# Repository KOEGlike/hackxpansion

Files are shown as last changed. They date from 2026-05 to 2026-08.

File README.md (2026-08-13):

> [!CAUTION]
> This repo has been moved to [hackclub/hackxpansion](https://github.com/hackclub/hackxpansion)

<h1 align="center">
    Hackxpansion
</h1>

<h3 align="center">
    <a href="https://hackxpansion.hackclub.com">Website</a>
    <br/>
    <a href="https://meko.fillout.com/hackxpansion">RSVP</a>
</h3>

<h4 align="center">
    A handheld console with 4 expansion solts
</h4>

<div align="center">
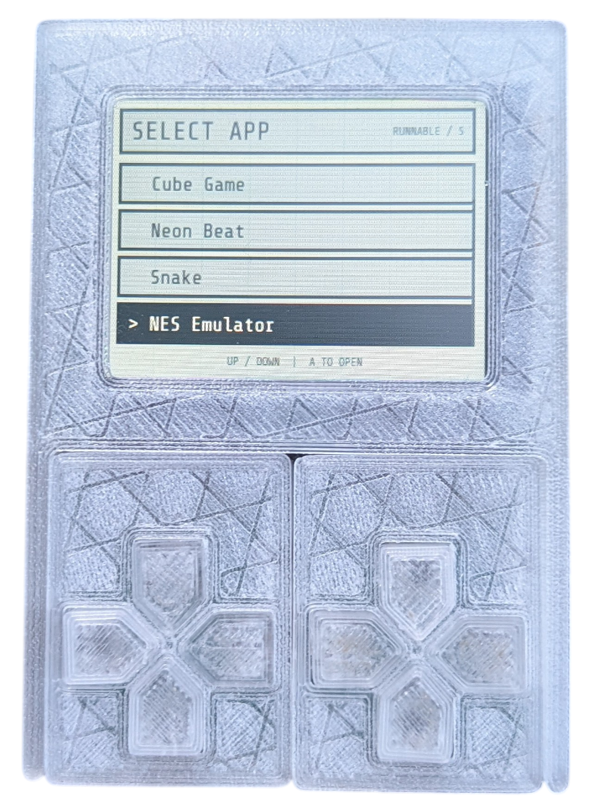
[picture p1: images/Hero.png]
    
</div>

## Key Features

- Resistor based module idnetification at start up
- [2" 240x320 ST7789 LCD panel](https://www.buydisplay.com/2-inch-ips-tft-lcd-display-ips-panel-screen-240x320-for-smart-watch)
- RP2354 MCU
- Easily adaptable [module standard](https://hackxpansion.dino.icu/docs/detailed/card)
- Rust firmware with [embassy](https://embassy.dev/) and [slint-ui](https://slint.dev/)

## Why?

I really like the idea of modules, and modular things, and making people work together, so I made this.

## PCB

The console has two 4 layer PCBs designed in KiCAD, a main-board and a daughter-board, designed for JLC's basic process. 

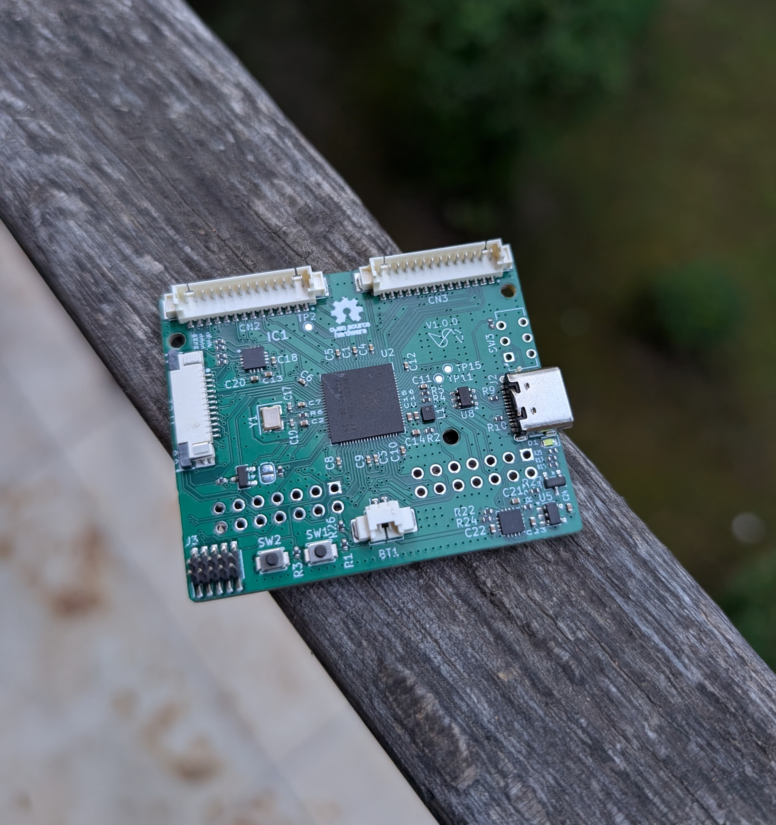
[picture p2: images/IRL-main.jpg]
irl pcb without some connectors and swithc


### Main-Board

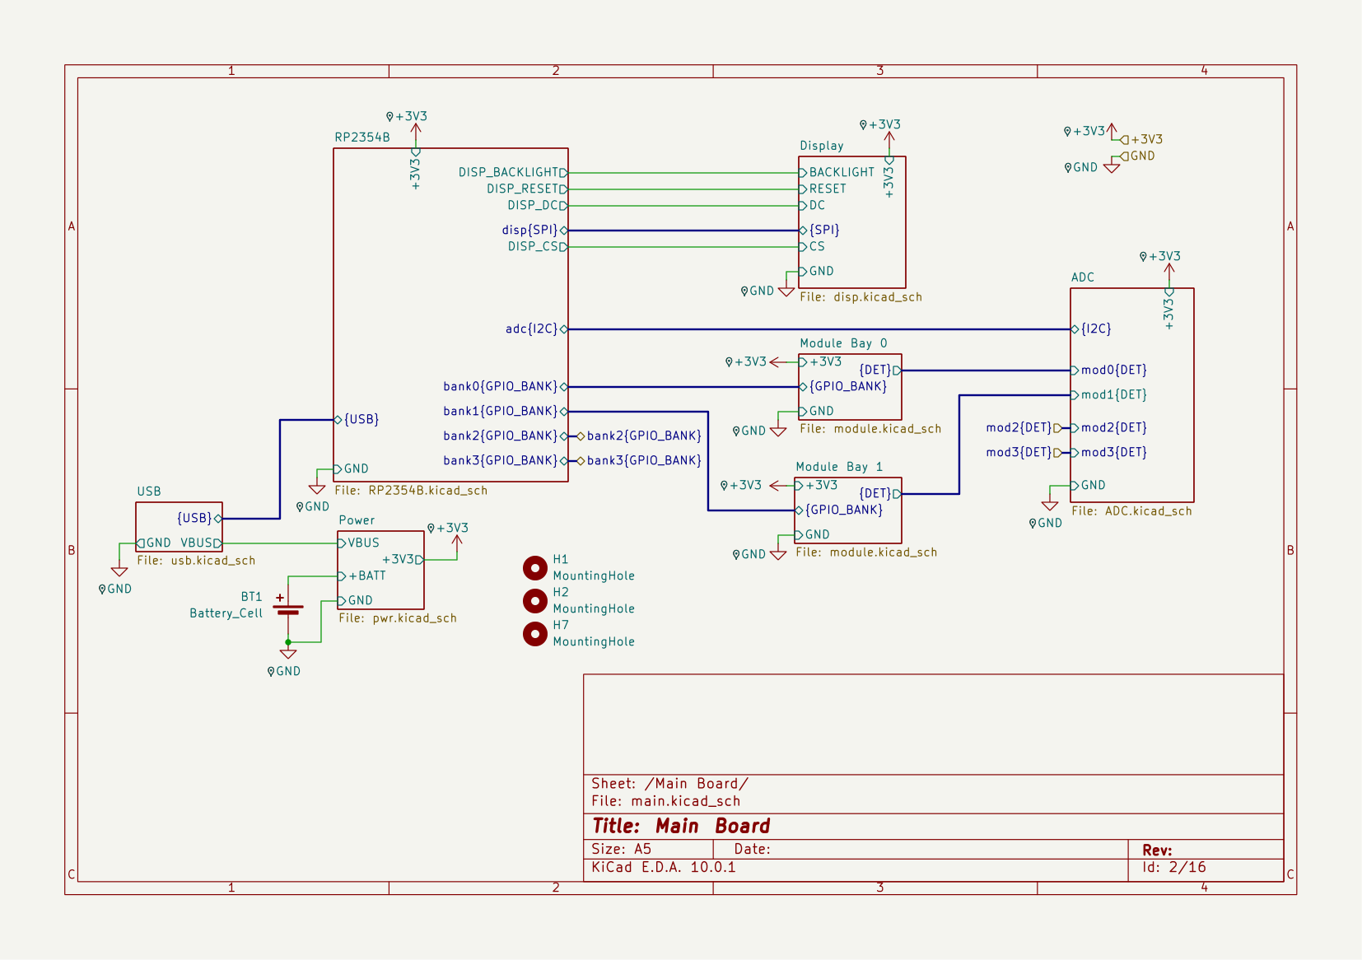
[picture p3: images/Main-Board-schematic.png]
main-board schematic

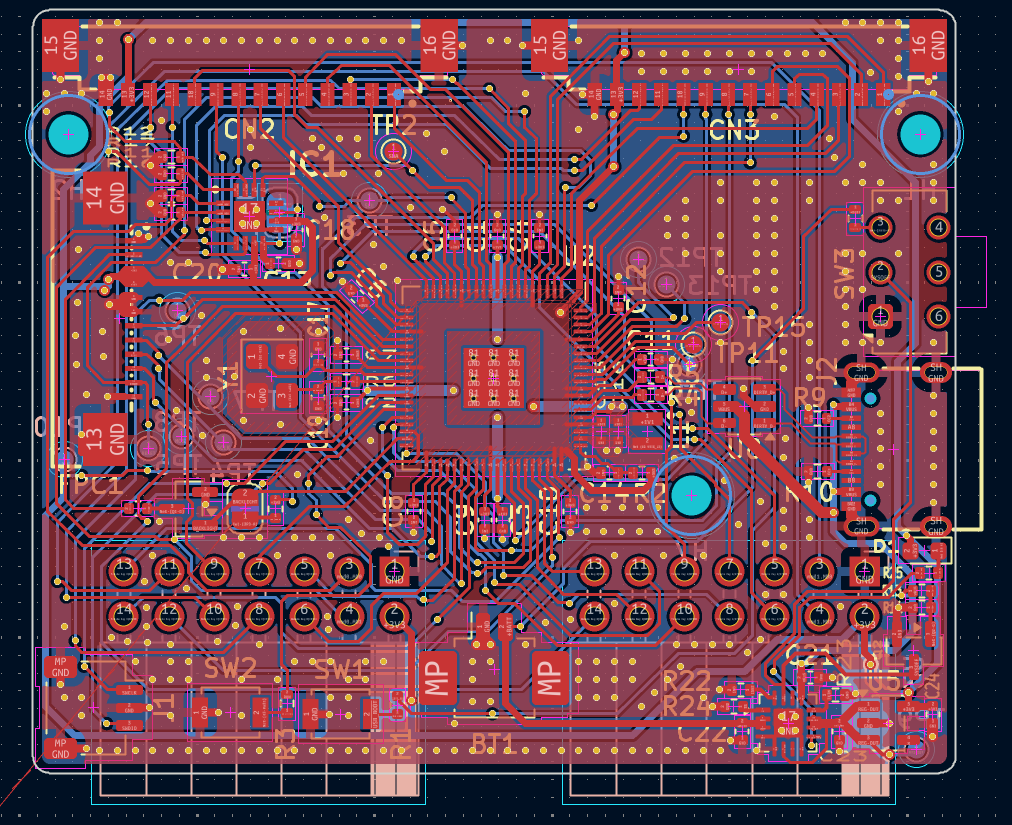
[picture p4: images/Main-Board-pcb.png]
main-board pcb

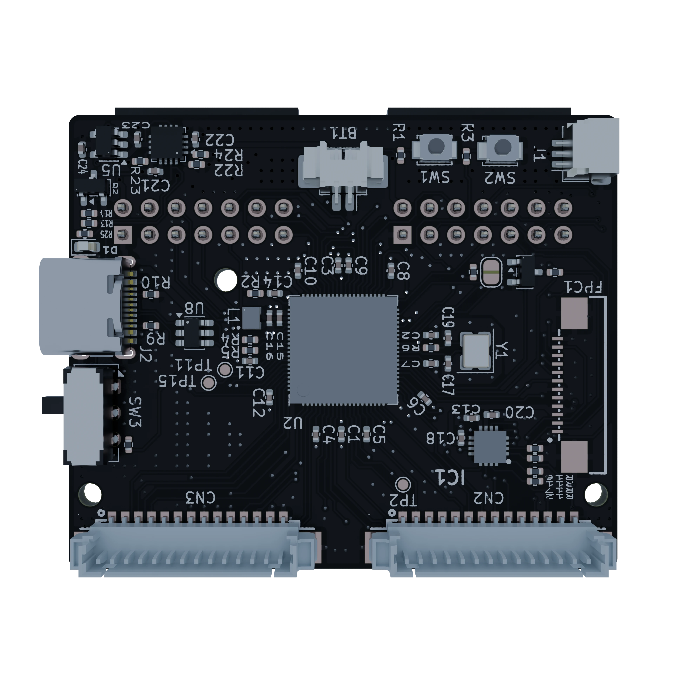
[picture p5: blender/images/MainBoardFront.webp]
main-board render


### Daughter-Board

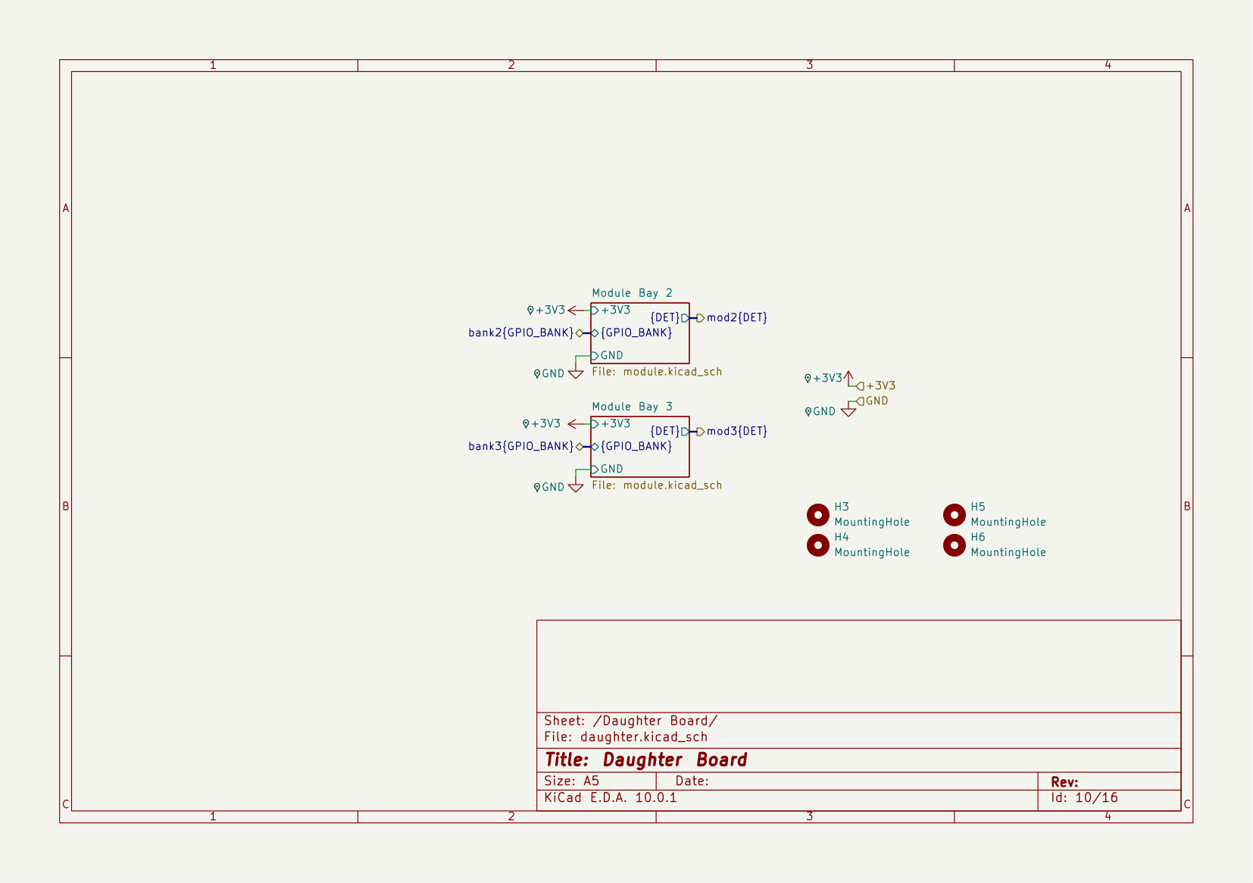
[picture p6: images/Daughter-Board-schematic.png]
daughter-board schematic

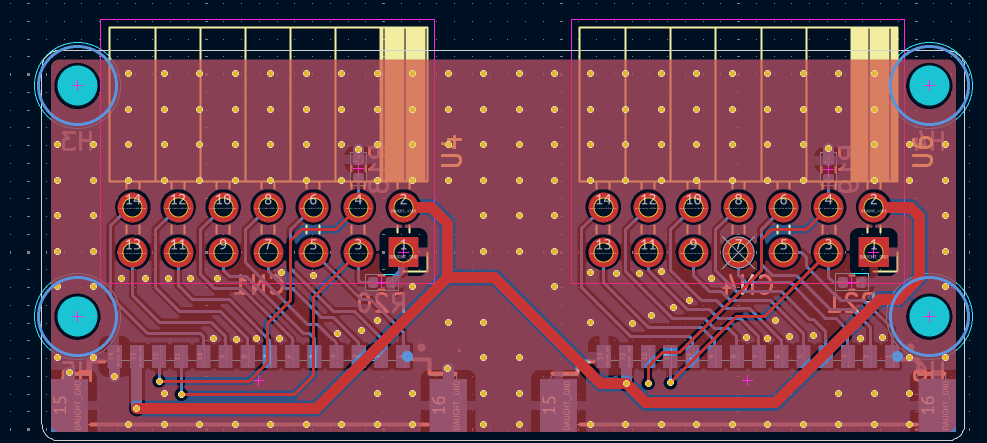
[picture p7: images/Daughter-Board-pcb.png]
daughter-board pcb

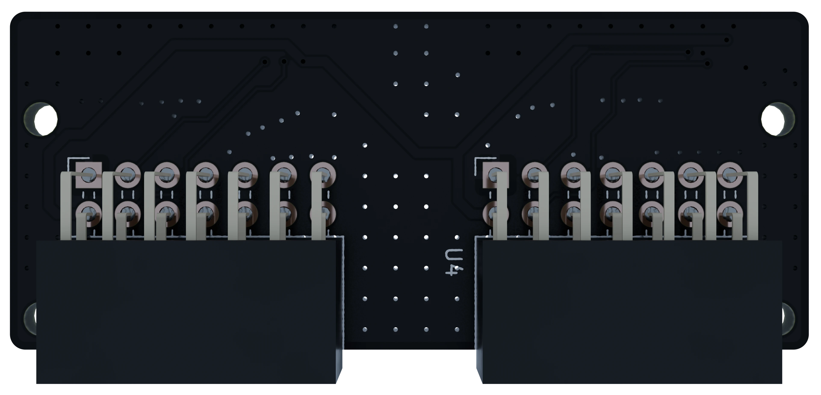
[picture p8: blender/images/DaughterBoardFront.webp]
daughter-board render


## Making Your Own Modules

There are three simple steps to making your own module:

1. Design the module PCB in KiCAD
2. Design the module case in CAD
3. Write a driver for the module

There are detailed docs on the [hackxpansion website](https://hackxpansion.dino.icu/docs)

## Case

The case is designed in Autodesk Fusion, there are .f3z files in the hardware directory.

The models have parameters that can be adjusted to fit your needs.

## Shoutouts

Thank you so much for [Simon](https://github.com/NEOgHacking) who helped with the fanout of the RP, and also gave a ton of constructive feedback!!!!

## Zine

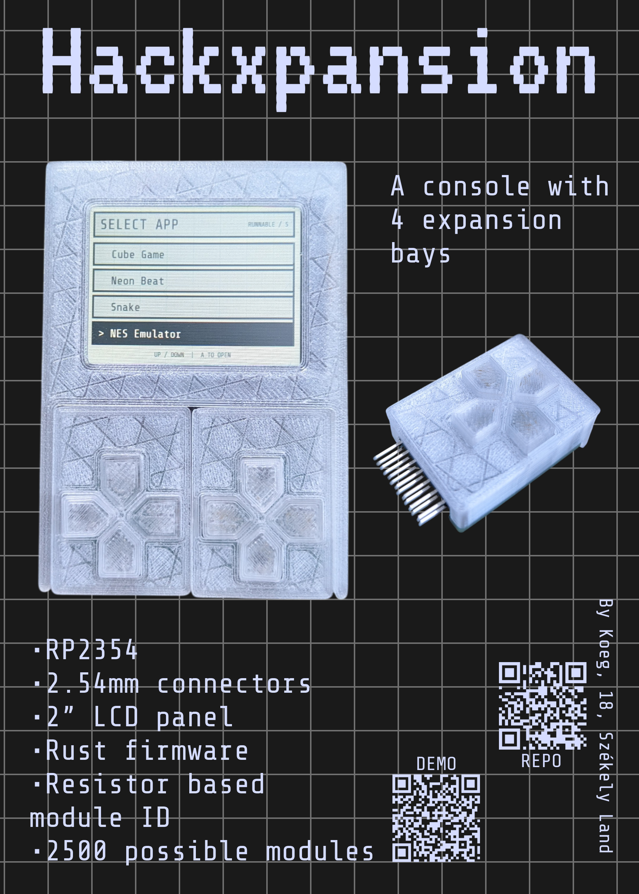
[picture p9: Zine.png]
magazine page


## BOM for Console

This is for an order of 2 PCBA PCBs.

Also found in a [CSV file](hardware/hackxpansion/BOM.csv). Each component has an LCSC part number attached that can be used to find the component on the LCSC website.

|Item |Price per unit|Nr of units|Total price|Link |
|---|---|---|---|---|
|PCB with PCBA |$60.00 |1 |$60.00 |https://jlcpcb.com/ |
|Display |$4.36 |1 |$4.36 |https://www.buydisplay.com/2-inch-ips-tft-lcd-display-ips-panel-screen-240x320-for-smart-watch|
|2x7 2.54mm header |$0.386 |10 |$3.860 |https://www.aliexpress.com/item/1005012166781874.html |
|Battery 502035 |$6.64 |1 |$6.64 |https://www.aliexpress.com/item/1005008218024646.html |
|M2 OD3 L2 heat set insert |$0.0696 |15 |$1.0440 |https://www.aliexpress.com/item/1005006798286851.html |
|M2 L6 screw |$0.0766 |5 |$0.3830 |https://www.aliexpress.com/item/4000970993800.html |
|M2 L8 screw |$0.0766 |2 |$0.1532 |https://www.aliexpress.com/item/4000970993800.html |
|M2 L4 screw |$0.0766 |8 |$0.6128 |https://www.aliexpress.com/item/4000970993800.html |
| | |Total: |$77.05 | |

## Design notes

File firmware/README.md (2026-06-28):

# Xpanse

> [!WARNING]  
> This is still under development and may contain bugs and the api may change, and many parts aren't documented.

This is the firmware for the Hackxpansion console.

The main binary create is called `xpanse`, this is the create the is the heart of the firmware.

The driver api is located in the `xpanse-api` create, this create provides drivers and apps with the necessary traits and types that they need to implement.

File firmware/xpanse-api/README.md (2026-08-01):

# Xpanse API

Shared API for xpanse apps, module drivers, and platform firmware for the [Hackxpansion](https://github.com/KOEGlike/hackxpansion) console

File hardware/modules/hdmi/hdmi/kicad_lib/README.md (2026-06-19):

# Hackxpansion KiCAD Lib

This library contatins the symbols for the male and female module connectors

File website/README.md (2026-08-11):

# Hackxpansion Website

SvelteKit website for the landing page, documentation, authenticated project tracking, and Ari
review integration.

## Requirements

- Node.js 22.12 or newer
- PostgreSQL 18
- Docker (user needs to be added to docker user group)

## Development

Install dependencies and configure the variables documented in `.env.example`. Start the local
database and apply the current Drizzle schema:

```sh
npm install
npm run db:start
npm run db:migrate
```

Then start SvelteKit:

```sh
npm run dev
```

Use `npm run db:generate` when creating a new migration from the current schema. Commit the generated
SQL and metadata together.

## Production

The application requires a Node server for authentication, database-backed pages, form actions, and
Ari webhooks. It cannot be hosted as a static GitHub Pages site.

```sh
npm ci
npm run build
ORIGIN=https://example.com HOST=127.0.0.1 PORT=3000 npm start
```

Set `BASE_PATH` while building when the server is mounted below the origin root. Place a reverse
proxy in front of the Node process for TLS and configure it to forward the original host and protocol.

Set `DATABASE_URL` to the managed PostgreSQL URL. If the deployment platform reserves or overrides
`DATABASE_URL`, set `APP_DATABASE_URL` instead; it takes precedence for migrations and the app.

Deploy production from the root `Dockerfile`. The container applies pending Drizzle migrations
before starting the server, serializing concurrent starts with a PostgreSQL advisory lock.

## Local Docker Compose

Configure `.env`, then build and start the app and local PostgreSQL database:

```sh
docker compose up --build -d
```

The application container applies pending Drizzle migrations before starting the server. Concurrent
starts are serialized with a PostgreSQL advisory lock. The application stack can be started with
`npm run compose:up`.

The app is served at `http://localhost:3000` by default. Set `APP_PORT` to change the host port:

```sh
APP_PORT=8080 docker compose up --build -d
```

Set `ORIGIN` to the public application URL in the runtime environment when deploying the Docker
image.

Generate and commit a new migration with `npm run db:generate` whenever the schema changes.

The initial migration expects a fresh database. A database previously initialized with `db:push`
has no Drizzle migration history; recreate that database or baseline it before enabling automatic
migrations if its existing data must be preserved.

## Quality Checks

```sh
npm run check
npm run lint
npm test
```

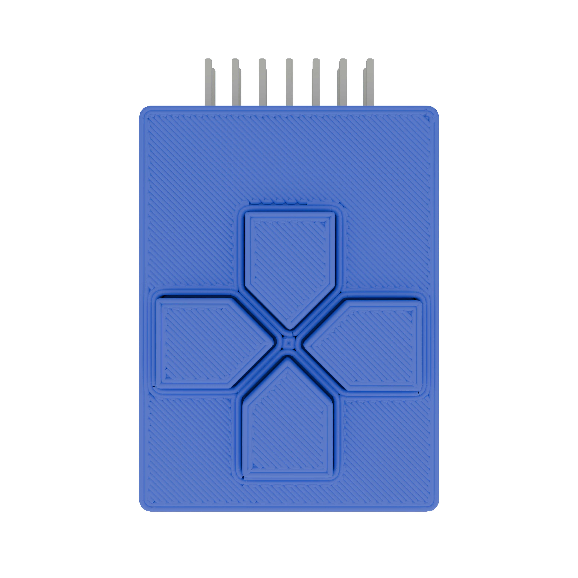
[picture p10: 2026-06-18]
blender/images/ModuleTopView.webp

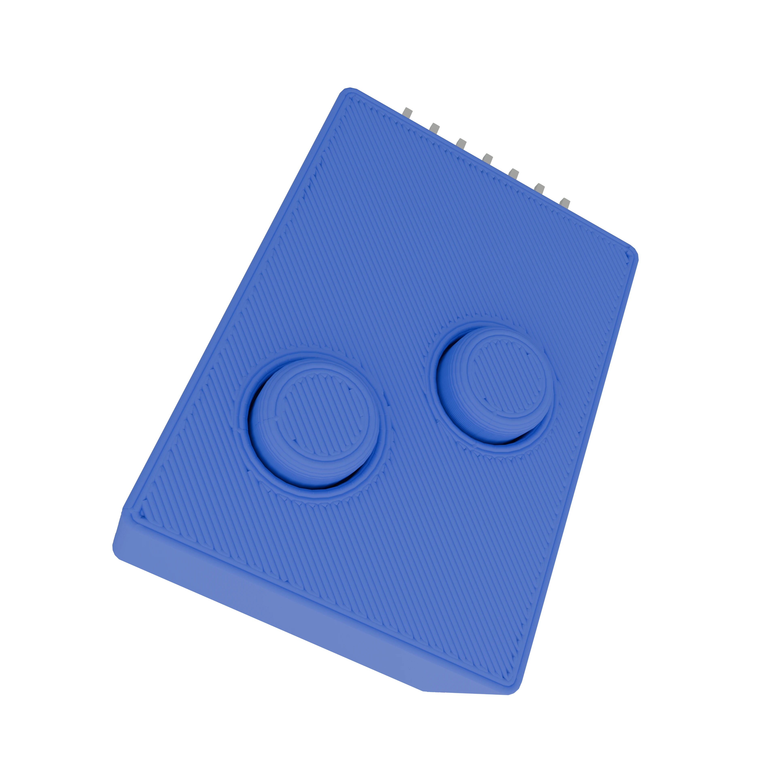
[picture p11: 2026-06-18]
blender/images/TwoButton.webp

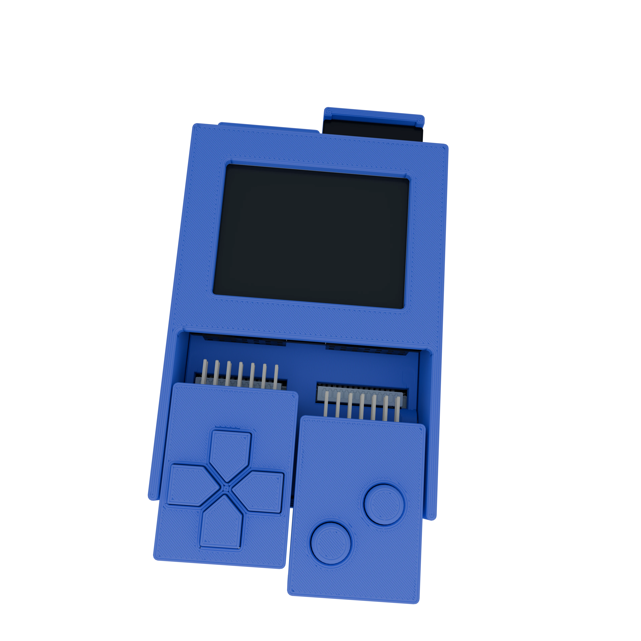
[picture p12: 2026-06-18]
blender/images/Hero.webp

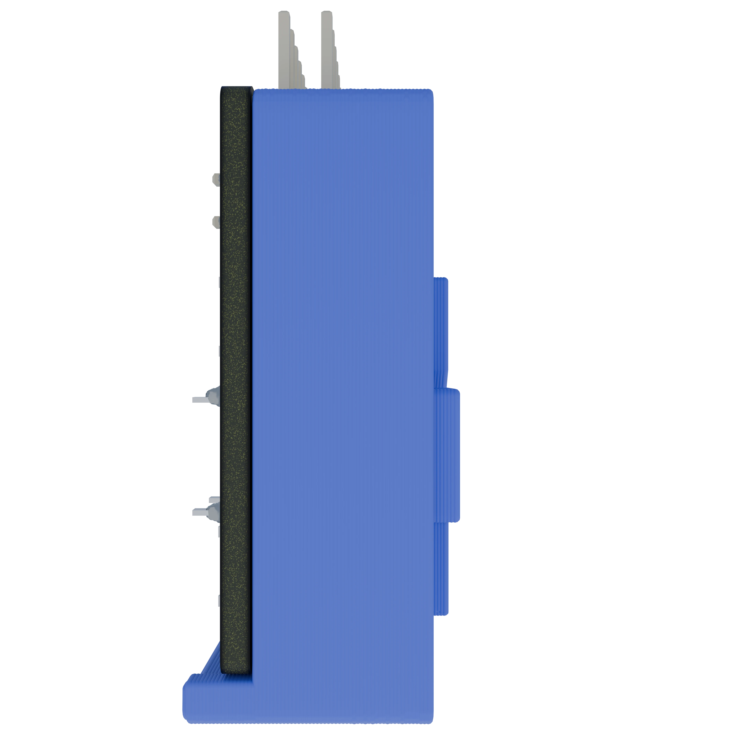
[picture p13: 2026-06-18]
blender/images/ModuleSideView.webp

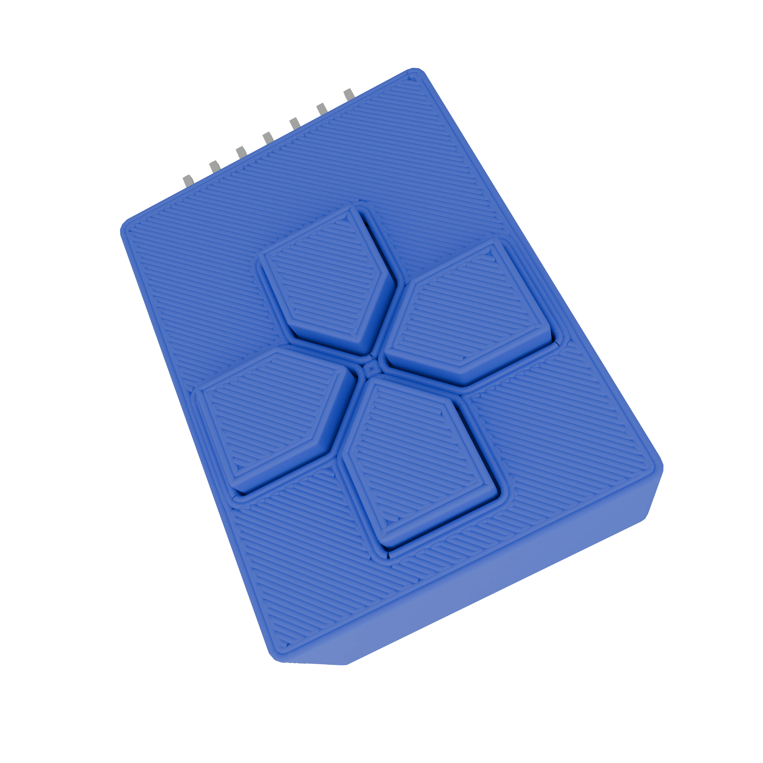
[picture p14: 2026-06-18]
blender/images/DPad.webp

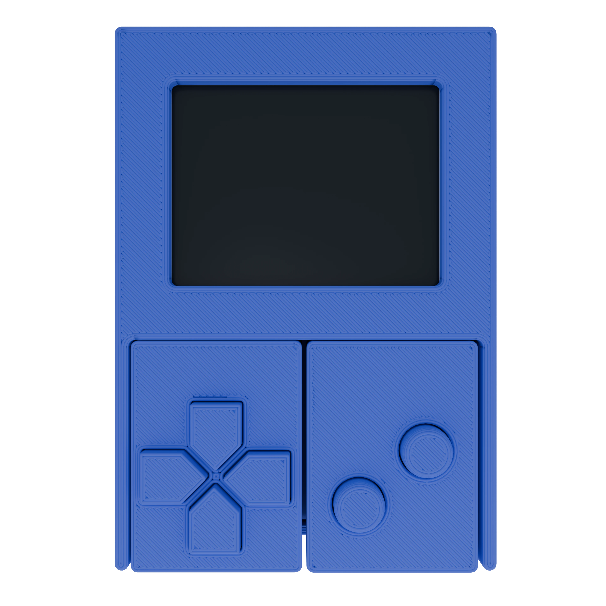
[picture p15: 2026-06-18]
blender/images/TopView.webp

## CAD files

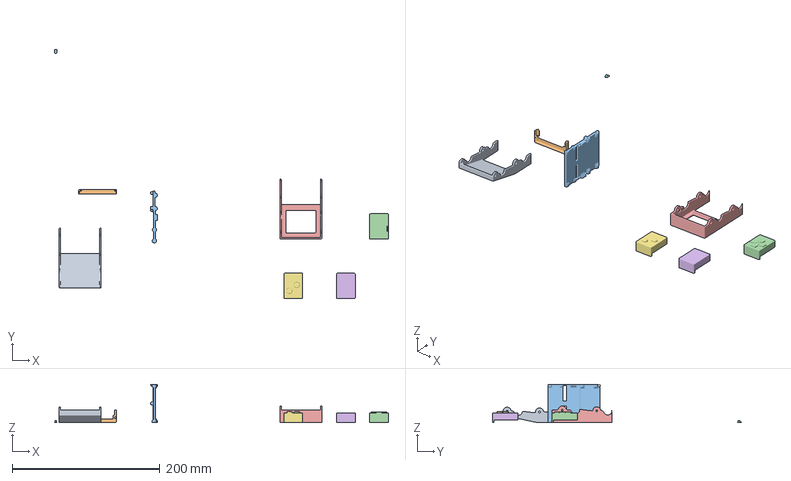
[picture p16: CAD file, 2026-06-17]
blender/gcode/prusa_project.3mf
452.4 x 337.8 x 52.0 mm
Back Shell
Battery Retainer
Core Plate
Four Button Module
Front Shell
empry Case
Two Button
Switch Cover

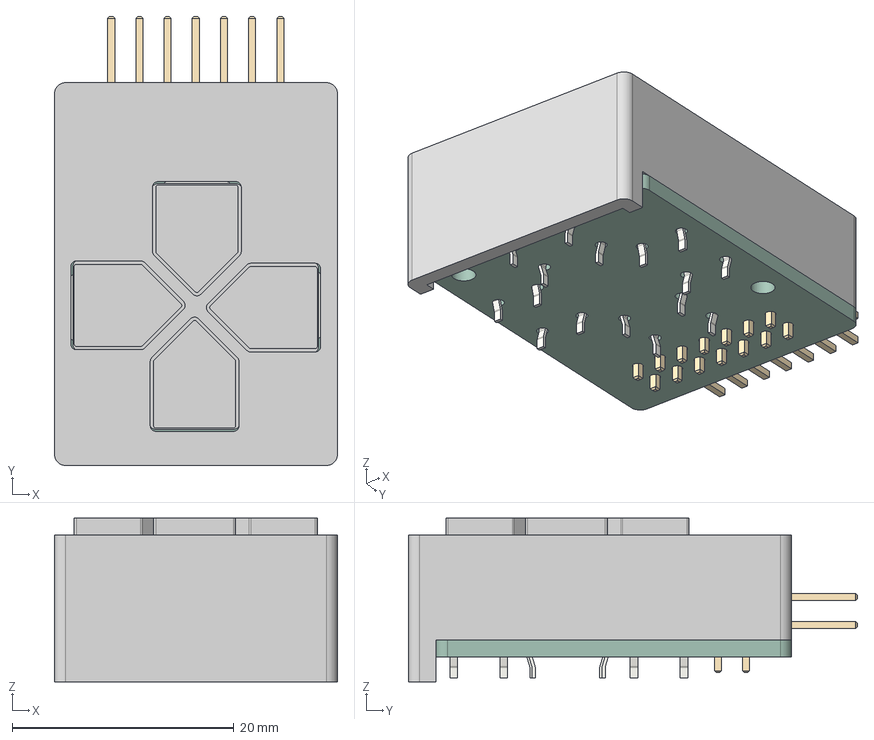
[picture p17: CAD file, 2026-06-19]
hardware/modules/four_button/Four Button Module.step
25.5 x 40.5 x 14.8 mm
PinHeader_2x07_P2.54mm_Horizontal
R_0805_2012Metric x 2
SW_PUSH_6mm x 4
four_button_PCB
Case
Button x 4

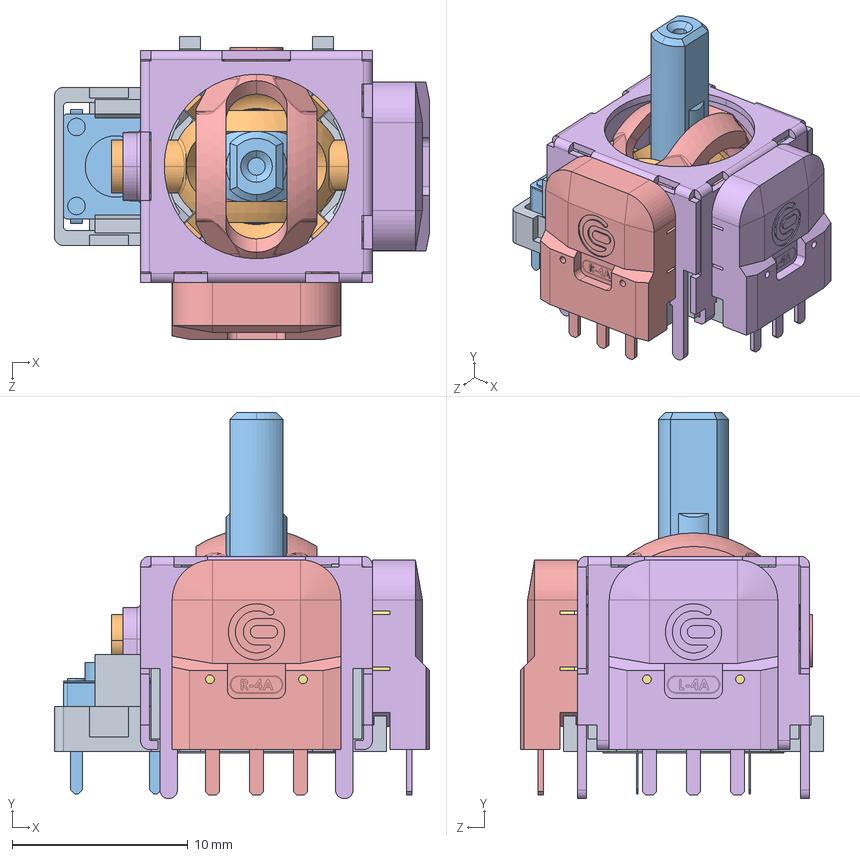
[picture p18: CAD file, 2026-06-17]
hardware/modules/joystick/pcb/Joystick_Hall_PS4.STEP
21.3 x 22.0 x 17.3 mm
Base
Resorte
Pulsador 6x6 5mm
Muelle
X
Stich
Base_Iman - Negro
Iman x 2
Y
Base_Iman
Palo
Eje
Sensor_Negro
Sensor

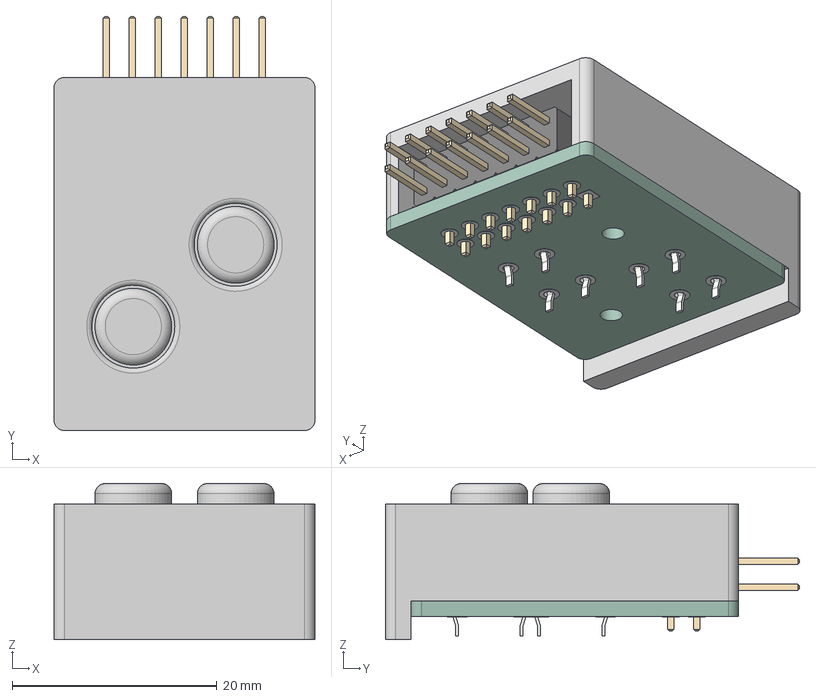
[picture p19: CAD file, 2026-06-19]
hardware/modules/two_button/Two Button.step
25.5 x 40.5 x 15.2 mm
PinHeader_2x07_P2.54mm_Horizontal
R_0805_2012Metric x 2
SW_PUSH_6mm x 2
two_button_pad
two_button_silkscreen
two_button_PCB
Case
Button Cap x 2

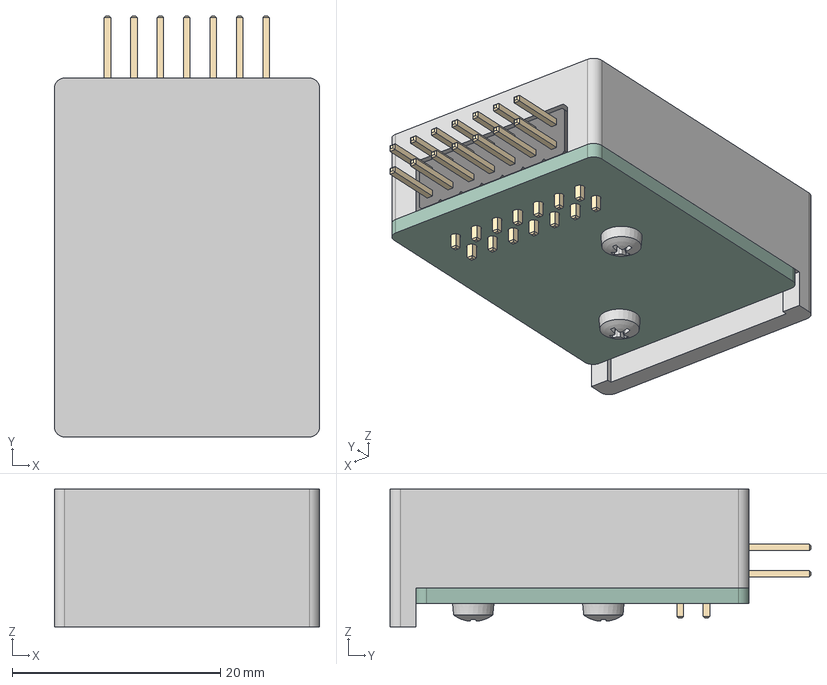
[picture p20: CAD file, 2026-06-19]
hardware/tutorials/audio_module/audio_module.step
25.5 x 40.5 x 13.2 mm
PinHeader_2x07_P2.54mm_Horizontal
R_0805_2012Metric x 2
empty_PCB
Case
DIN 7985 - M2x5-H H Steel 4.6 Plain x 2

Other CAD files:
blender/hackxpansion.blend
hardware/hackxpansion/Main.f3z
hardware/modules/four_button/Four Button Module.f3d
hardware/modules/joystick/pcb/Joystick_Hall_PS4.IGS
hardware/modules/two_button/Two Button.f3d
hardware/tutorials/audio_module/audio_module.f3z
website/animation/anim.blend
website/animation/mockup.f3d

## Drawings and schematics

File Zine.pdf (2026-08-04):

# Hackxpansion

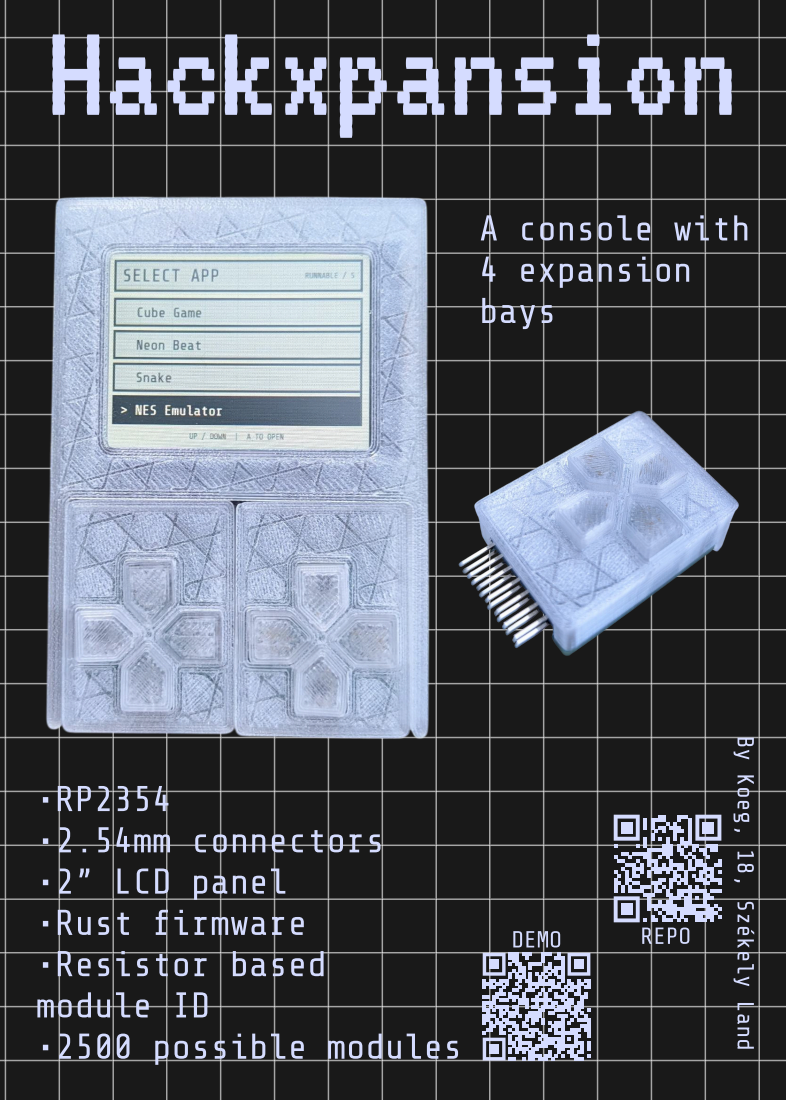
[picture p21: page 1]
A console; with; 4 expansion bays; •RP2354 •2.54mm connectors •2” LCD panel •Rust firmware •Resistor based module ID •2500 possible modules; DEMO; REPO

By Koeg, 18, Székely Land

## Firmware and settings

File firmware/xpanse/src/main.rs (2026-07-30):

#![no_std]
#![no_main]

extern crate alloc;

use defmt::*;
use embassy_executor::Executor;
use embassy_rp::multicore::{Stack, spawn_core1};
use embedded_alloc::LlffHeap as Heap;
use static_cell::StaticCell;
use xpanse::{
    core_app::ui_core_task, core_driver::app_core_task, resource_split::*, split_resources,
};
use {defmt_rtt as _, panic_probe as _};

// Program metadata for `picotool info`.
// This isn't needed, but it's recommended to have these minimal entries.
#[unsafe(link_section = ".bi_entries")]
#[used]
pub static PICOTOOL_ENTRIES: [embassy_rp::binary_info::EntryAddr; 4] = [
    embassy_rp::binary_info::rp_program_name!(c"Hackxpansion"),
    embassy_rp::binary_info::rp_program_description!(c"Firmware for Hackxpansion"),
    embassy_rp::binary_info::rp_cargo_version!(),
    embassy_rp::binary_info::rp_program_build_attribute!(),
];

static mut CORE1_STACK: Stack<16384> = Stack::new();
static EXECUTOR0: StaticCell<Executor> = StaticCell::new();
static EXECUTOR1: StaticCell<Executor> = StaticCell::new();

#[global_allocator]
static HEAP: Heap = Heap::empty();
const HEAP_SIZE: usize = 64 * 1024;

#[cortex_m_rt::entry]
fn main() -> ! {
    let p = embassy_rp::init(Default::default());
    info!("boot: RP235x peripherals initialized");

    let r = split_resources!(p);
    info!("boot: board resources assigned");

    unsafe {
        embedded_alloc::init!(HEAP, HEAP_SIZE);
    }
    info!("boot: {} KiB heap initialized", HEAP_SIZE / 1024);

    info!("boot: starting core 1");
    spawn_core1(
        p.CORE1,
        unsafe { &mut *core::ptr::addr_of_mut!(CORE1_STACK) },
        move || {
            let executor1 = EXECUTOR1.init(Executor::new());
            executor1.run(|spawner| {
                spawner.spawn(unwrap!(app_core_task(
                    r.gpio_bank_0,
                    r.gpio_bank_1,
                    r.gpio_bank_2,
                    r.gpio_bank_3,
                    r.i2c_pins,
                    r.remaining_peris
                )))
            });
        },
    );
    info!("boot: core 1 launched");

    info!("boot: starting core 0 UI executor");
    let executor0 = EXECUTOR0.init(Executor::new());
    executor0.run(|spawner| spawner.spawn(unwrap!(ui_core_task(r.display))));
}

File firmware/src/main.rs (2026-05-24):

//! This example test the RP Pico on board LED.
//!
//! It does not work with the RP Pico W board. See `blinky_wifi.rs`.

#![no_std]
#![no_main]

use defmt::*;
use embassy_executor::Spawner;
use embassy_rp::gpio;
use embassy_time::Timer;
use gpio::{Level, Output};
use heapless::String;
use {defmt_rtt as _, panic_probe as _};

// Program metadata for `picotool info`.
// This isn't needed, but it's recommended to have these minimal entries.
#[unsafe(link_section = ".bi_entries")]
#[used]
pub static PICOTOOL_ENTRIES: [embassy_rp::binary_info::EntryAddr; 4] = [
    embassy_rp::binary_info::rp_program_name!(c"Hackxpansion"),
    embassy_rp::binary_info::rp_program_description!(
        c"This example tests the RP Pico on board LED, connected to gpio 25"
    ),
    embassy_rp::binary_info::rp_cargo_version!(),
    embassy_rp::binary_info::rp_program_build_attribute!(),
];

#[embassy_executor::main]
async fn main(_spawner: Spawner) {
    let p = embassy_rp::init(Default::default());
    let mut led = Output::new(p.PIN_25, Level::Low);

    loop {
        info!("led on!");
        led.set_high();
        Timer::after_millis(250).await;

        info!("led off!");
        led.set_low();
        Timer::after_millis(250).await;
    }
}

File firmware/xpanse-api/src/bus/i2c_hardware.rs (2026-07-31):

//! RP235x hardware I2C backend, interrupt-driven with no DMA.
//!
//! The platform normally constructs these buses through
//! [`BusAllocator::create_i2c_hardware`](crate::bus::allocator::BusAllocator::create_i2c_hardware).
use alloc::vec::Vec;

use crate::bus::i2c::I2cError;
use embassy_rp::Peri;
use embassy_rp::i2c::{self, Async, Config, I2c, Instance, InterruptHandler};
use embassy_rp::interrupt::typelevel::Binding;

/// Interrupt-driven RP235x I2C bus implementing
/// [`embedded_hal_async::i2c::I2c`] for `I2cBusHandle`.
pub struct HardwareI2cBus<'d, I: Instance> {
    i2c: I2c<'d, I, Async>,
}

impl<'d, I: Instance> HardwareI2cBus<'d, I> {
    /// Validates an I2C configuration against the running peripheral clock.
    ///
    /// Returns [`I2cError::Other`] when the frequency and derived divider counts
    /// fall outside the hardware's representable range.
    pub fn validate_config(config: &Config) -> Result<(), I2cError> {
        if config.frequency == 0 || config.frequency > 1_000_000 {
            return Err(I2cError::Other);
        }

        let clock = embassy_rp::clocks::clk_peri_freq();
        let period = (clock + config.frequency / 2) / config.frequency;
        let low_count = period * 3 / 5;
        let high_count = period - low_count;
        if high_count < 8 || low_count < 8 || high_count > 0xffff || low_count > 0xffff {
            return Err(I2cError::Other);
        }

        let sda_hold_count = if config.frequency < 1_000_000 {
            ((clock * 3) / 10_000_000) + 1
        } else {
            if clock <= 32_000_000 {
                return Err(I2cError::Other);
            }
            ((clock * 3) / 25_000_000) + 1
        };
        if sda_hold_count > low_count - 2 {
            return Err(I2cError::Other);
        }

        Ok(())
    }

    /// Builds an I2C bus from a previously validated configuration.
    ///
    /// `scl` and `sda` are role-checked against `I` at compile time, and `irq`
    /// is the board's `bind_interrupts!` binding for the I2C interrupt.
    pub fn new<Irq>(
        peri: Peri<'d, I>,
        scl: Peri<'d, impl i2c::SclPin<I> + 'd>,
        sda: Peri<'d, impl i2c::SdaPin<I> + 'd>,
        irq: Irq,
        config: Config,
    ) -> Result<Self, I2cError>
    where
        Irq: Binding<I::Interrupt, InterruptHandler<I>> + 'd,
    {
        Self::validate_config(&config)?;
        let i2c = I2c::new_async(peri, scl, sda, irq, config);
        Ok(Self { i2c })
    }
}

impl<'d, I: Instance> embedded_hal::i2c::ErrorType for HardwareI2cBus<'d, I> {
    type Error = I2cError;
}

impl<'d, I: Instance> embedded_hal_async::i2c::I2c<embedded_hal::i2c::SevenBitAddress>
    for HardwareI2cBus<'d, I>
{
    async fn read(
        &mut self,
        address: embedded_hal::i2c::SevenBitAddress,
        read: &mut [u8],
    ) -> Result<(), I2cError> {
        if address > 0x7f {
            return Err(I2cError::AddressOutOfRange);
        }
        if read.is_empty() {
            return Err(I2cError::InvalidBufferLength);
        }
        self.i2c.read(address, read).await.map_err(I2cError::from)
    }

    async fn write(
        &mut self,
        address: embedded_hal::i2c::SevenBitAddress,
        write: &[u8],
    ) -> Result<(), I2cError> {
        if address > 0x7f {
            return Err(I2cError::AddressOutOfRange);
        }
        if write.is_empty() {
            return Err(I2cError::InvalidBufferLength);
        }
        self.i2c.write(address, write).await.map_err(I2cError::from)
    }

    async fn write_read(
        &mut self,
        address: embedded_hal::i2c::SevenBitAddress,
        write: &[u8],
        read: &mut [u8],
    ) -> Result<(), I2cError> {
        if address > 0x7f {
            return Err(I2cError::AddressOutOfRange);
        }
        if write.is_empty() || read.is_empty() {
            return Err(I2cError::InvalidBufferLength);
        }
        self.i2c
            .write_read(address, write, read)
            .await
            .map_err(I2cError::from)
    }

    async fn transaction(
        &mut self,
        address: embedded_hal::i2c::SevenBitAddress,
        operations: &mut [embedded_hal::i2c::Operation<'_>],
    ) -> Result<(), I2cError> {
        if address > 0x7f {
            return Err(I2cError::AddressOutOfRange);
        }
        if operations.iter().any(|operation| match operation {
            embedded_hal::i2c::Operation::Read(buf) => buf.is_empty(),
            embedded_hal::i2c::Operation::Write(buf) => buf.is_empty(),
        }) {
            return Err(I2cError::InvalidBufferLength);
        }
        if operations.is_empty() {
            return Ok(());
        }

        let mut seen_read = false;
        let mut write_len = 0;
        let mut read_len = 0;
        for operation in operations.iter() {
            match operation {
                embedded_hal::i2c::Operation::Write(bytes) if !seen_read => {
                    write_len += bytes.len();
                }
                embedded_hal::i2c::Operation::Read(bytes) => {
                    seen_read = true;
                    read_len += bytes.len();
                }
                embedded_hal::i2c::Operation::Write(_) => {
                    // The public Embassy API cannot continue an atomic transaction
                    // after a read phase, so reject rather than insert a STOP.
                    return Err(I2cError::UnsupportedTransaction);
                }
            }
        }

        let mut write_buffer = Vec::with_capacity(write_len);
        for operation in operations.iter() {
            if let embedded_hal::i2c::Operation::Write(bytes) = operation {
                write_buffer.extend_from_slice(bytes);
            }
        }

        if read_len == 0 {
            return self
                .i2c
                .write(address, &write_buffer)
                .await
                .map_err(I2cError::from);
        }

        let mut read_buffer = alloc::vec![0; read_len];
        if write_len == 0 {
            self.i2c
                .read(address, &mut read_buffer)
                .await
                .map_err(I2cError::from)?;
        } else {
            self.i2c
                .write_read(address, &write_buffer, &mut read_buffer)
                .await
                .map_err(I2cError::from)?;
        }

        let mut offset = 0;
        for operation in operations.iter_mut() {
            if let embedded_hal::i2c::Operation::Read(bytes) = operation {
                let end = offset + bytes.len();
                bytes.copy_from_slice(&read_buffer[offset..end]);
                offset = end;
            }
        }
        Ok(())
    }
}

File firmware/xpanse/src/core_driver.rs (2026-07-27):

use xpanse_api::gpio_bank::GpioBank;
use xpanse_api::registry::Registry;

use crate::load_driver::load_driver;
use crate::{adc::init_adc, adc_mapping, resource_split::*};
use xpanse_api::bus::allocator::BusAllocator;
use xpanse_api::interfaces::adc;
use xpanse_api::interfaces::usb::UsbPeripheral;
use xpanse_api::metadata::{ModuleID, ModuleSlot};

use embassy_sync::{blocking_mutex::raw::CriticalSectionRawMutex, signal::Signal};
use embassy_time::{Duration, Timer, with_timeout};

const MODULE_DETECTION_TIMEOUT: Duration = Duration::from_millis(100);

macro_rules! gpio_bank_from_peris {
    ($peri:expr) => {
        GpioBank::new(
            $peri.gpio0,
            $peri.gpio1,
            $peri.gpio2,
            $peri.gpio3,
            $peri.gpio4,
            $peri.gpio5,
            $peri.gpio6,
            $peri.gpio7,
            $peri.gpio8,
            $peri.gpio9,
            $peri.pwm_slice1,
            $peri.pwm_slice2,
            $peri.pwm_slice3,
        )
    };
}

static REGISTRY_HANDOFF: Signal<CriticalSectionRawMutex, Registry> = Signal::new();

pub async fn take_registry() -> Registry {
    REGISTRY_HANDOFF.wait().await
}

#[embassy_executor::task]
pub async fn app_core_task(
    gpio_bank_0: GpioBankPeris0,
    gpio_bank_1: GpioBankPeris1,
    gpio_bank_2: GpioBankPeris2,
    gpio_bank_3: GpioBankPeris3,
    mut i2c_pins: I2cPinPeris,
    remaining_peris: RemainingPeris,
) {
    defmt::info!("app_core: started on core 1");

    let gpio_bank_0 = gpio_bank_from_peris!(gpio_bank_0);
    let gpio_bank_1 = gpio_bank_from_peris!(gpio_bank_1);
    let gpio_bank_2 = gpio_bank_from_peris!(gpio_bank_2);
    let gpio_bank_3 = gpio_bank_from_peris!(gpio_bank_3);
    defmt::info!("app_core: GPIO banks initialized");

    defmt::info!("app_core: initializing module-detection ADC");
    let module_ids = {
        let module_adc = match init_adc(i2c_pins.sda.reborrow(), i2c_pins.scl.reborrow()).await {
            Ok(adc) => {
                defmt::info!("app_core: module-detection ADC initialized");
                Some(adc)
            }
            Err(error) => {
                defmt::error!(
                    "app_core: module-detection ADC initialization failed: {:?}",
                    error
                );
                None
            }
        };

        match module_adc {
            Some(mut module_adc) => {
                let front_right = detect_module(&mut module_adc, ModuleSlot::FrontRight).await;
                let front_left = detect_module(&mut module_adc, ModuleSlot::FrontLeft).await;
                let back_right = detect_module(&mut module_adc, ModuleSlot::BackRight).await;
                let back_left = detect_module(&mut module_adc, ModuleSlot::BackLeft).await;
                [front_right, front_left, back_right, back_left]
            }
            None => [None; 4],
        }
    };

    defmt::info!("app_core: initializing internal ADC");
    adc::init_adc(remaining_peris.adc, remaining_peris.adc_temp);
    defmt::info!("app_core: internal ADC initialized");

    defmt::info!("app_core: creating bus allocator");
    let mut bus_allocator = BusAllocator::new(
        None,
        Some(remaining_peris.spi1),
        Some(remaining_peris.i2c0),
        Some(remaining_peris.i2c1),
        Some(remaining_peris.uart0),
        Some(remaining_peris.uart1),
        xpanse_api::bus::allocator::DmaPool {
            ch0: Some(remaining_peris.dma_ch0),
            ch1: Some(remaining_peris.dma_ch1),
            ch2: Some(remaining_peris.dma_ch2),
            ch3: Some(remaining_peris.dma_ch3),
            ch4: Some(remaining_peris.dma_ch4),
            ch5: Some(remaining_peris.dma_ch5),
            ch6: Some(remaining_peris.dma_ch6),
            ch7: Some(remaining_peris.dma_ch7),
            ch8: Some(remaining_peris.dma_ch8),
            ch9: Some(remaining_peris.dma_ch9),
            ch10: Some(remaining_peris.dma_ch10),
            ch11: Some(remaining_peris.dma_ch11),
            ch12: Some(remaining_peris.dma_ch12),
            ch13: Some(remaining_peris.dma_ch13),
            ch14: Some(remaining_peris.dma_ch14),
            ch15: Some(remaining_peris.dma_ch15),
        },
        remaining_peris.pio0,
        remaining_peris.pio1,
        remaining_peris.pio2,
    );

    let mut registry = Registry::new();
    registry.register_platform::<UsbPeripheral>(remaining_peris.usb);

    defmt::info!("app_core: loading module drivers");
    load_driver(
        module_ids[0],
        gpio_bank_0,
        ModuleSlot::FrontRight,
        &mut registry,
        &mut bus_allocator,
    )
    .await;
    load_driver(
        module_ids[1],
        gpio_bank_1,
        ModuleSlot::FrontLeft,
        &mut registry,
        &mut bus_allocator,
    )
    .await;
    load_driver(
        module_ids[2],
        gpio_bank_2,
        ModuleSlot::BackRight,
        &mut registry,
        &mut bus_allocator,
    )
    .await;
    load_driver(
        module_ids[3],
        gpio_bank_3,
        ModuleSlot::BackLeft,
        &mut registry,
        &mut bus_allocator,
    )
    .await;

    defmt::info!("app_core: drivers loaded, handing registry to core 0");
    REGISTRY_HANDOFF.signal(registry);
}

async fn detect_module(adc: &mut crate::adc::Adc<'_>, slot: ModuleSlot) -> Option<ModuleID> {
    defmt::info!("app_core: detecting module in {:?}", slot);

    for attempt in 1..=3 {
        match with_timeout(MODULE_DETECTION_TIMEOUT, adc_mapping::map_adc(adc, slot)).await {
            Ok(Ok(Some(id))) => {
                defmt::info!("app_core: detected module {:?} in {:?}", id, slot);
                return Some(id);
            }
            Ok(Ok(None)) => {
                defmt::info!("app_core: no module detected in {:?}", slot);
                return None;
            }
            Ok(Err(error)) => defmt::warn!(
                "app_core: module detection attempt {} failed for {:?}: {:?}",
                attempt,
                slot,
                error
            ),
            Err(_) => defmt::warn!(
                "app_core: module detection attempt {} timed out for {:?}",
                attempt,
                slot
            ),
        }
        Timer::after_millis(10).await;
    }
    defmt::error!("app_core: module detection failed for {:?}", slot);
    None
}

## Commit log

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2026-01-29 added mcu and adc
    [hackxpansion.kicad_sch]
2026-03-14 added basic blend file
    [Untitled.blend]
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2026-03-14 moved renders to different folder
    [Untitled.blend]
2026-03-14 added stuff related to loading
    [Untitled.blend, mockup.f3d]
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2026-03-15 updated anim to 60 fps
    [Untitled.blend, anim.blend, mockup.f3d]
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2026-03-15 Added RP2354B and made basic fanout
    [RP2354B.kicad_sch, hackxpansion.kicad_pcb, hackxpansion.kicad_sch]
2026-03-15 More fanout
    Just a little bit further with the fanout of the RP2354B
    [hackxpansion.kicad_pcb]
2026-03-16 Completed fanout
    Completed the fanout for the rp2354B also placed the silkscreen labels in places where you can read them.
    [hackxpansion.kicad_pcb, hackxpansion.kicad_sch]
2026-03-16 ADC Power and input
    Started with the power input and communication for the ADC
    [hackxpansion.kicad_sch]
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2026-03-16 fix: correct frame event start index and adjust element height for better scrolling
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2026-03-16 fix: conditionally render "Go Up" button based on current frame
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2026-03-17 fix: adjust scroll frame rate and update frame event end value
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2026-03-19 Fixed missing stuff and now finally separate sheet for the ADC
    Auto stash before merge of "main" and "origin/main"
    [ADC.kicad_sch, hackxpansion.kicad_sch]
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2026-03-19 feat: replace Scroll component with LandingSection for improved layout
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2026-03-23 Fixed 1V1 trace and added a bit to ADC schematic
    [ADC.kicad_sch, RP2354B.kicad_sch, hackxpansion.kicad_pcb]
2026-03-24 added jlc 2 layer constraints
    [ADC.kicad_sch]
2026-03-24 moved to kicad 10
    [ADC.kicad_sch, RP2354B.kicad_sch, hackxpansion.kicad_pcb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]
2026-03-30 added new adc symbol
    [hackxpansion.kicad_pcb, hackxpansion.kicad_sch]
2026-03-30 finished adding new adc, and started on dispaly
    [ADC.kicad_sch, disp.kicad_sch, hackxpansion.kicad_pcb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]
2026-04-09 STARTED WORKING ON SYMBOL
    [disp.kicad_sch, hackxpansion.kicad_pcb, hackxpansion.kicad_sch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]
2026-04-09 moved stuff around, started on display
    [RP2354B.kicad_sch, disp.kicad_sch]
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2026-04-26 updated power sheet, made module female symbol
    [module.kicad_sch, pwr.kicad_sch]
2026-05-03 removed unused power symbols
    [pwr.kicad_sch]
2026-05-07 worked on io banks
    [ADC.kicad_sch, CONNECTOR.csv, RP2354B.kicad_sch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]
2026-05-07 did a bunch of gpio bank stuff
    [CONNECTOR.csv, RP2354B.kicad_sch, disp.kicad_sch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]
2026-05-17 started to split up the schematic into two pcbs
    [ADC.kicad_sch, RP2354B.kicad_sch, daughter.kicad_sch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]
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2026-05-18 switched to pico blade connectors
    [daughter_conn.kicad_sch, hackxpansion.kicad_pcb, hackxpansion.kicad_sch]
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2026-05-20 updated some stuff on pcb
    [disp.kicad_sch, hackxpansion.kicad_pcb]
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2026-05-21 laid out edge components
    [hackxpansion.kicad_pcb]
2026-05-21 did more layout, added 3d models
    [RP2354B.kicad_sch, disp.kicad_sch, hackxpansion.kicad_pcb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]
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2026-05-22 worked on the pcb
    [ADC.kicad_sch, RP2354B.kicad_sch, disp.kicad_sch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]
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2026-05-23 swapped the module pins around
    [RP2354B.kicad_sch, hackxpansion.kicad_pcb, main.kicad_sch]
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2026-05-28 added some stitching vias
    [hackxpansion.kicad_pcb]
2026-05-28 added more stitching vias
    [hackxpansion.kicad_pcb]
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2026-05-28 laid out secound module
    [hackxpansion.kicad_pcb]
2026-05-29 finished daughter board, added stuff to main board
    added esd and extra mounting hole to mainboard, finished daughter board
    [daughter.kicad_sch, hackxpansion.kicad_pcb, main.kicad_sch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]
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2026-05-30 restructured project, added two button example module
    [ADC.kicad_sch, RP2354B.kicad_sch, daughter.kicad_sch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]
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2026-05-31 removed display brightness control, ran out of pin
    [RP2354B.kicad_sch, disp.kicad_sch, hackxpansion.kicad_pcb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]
2026-06-01 added titles to schematic
    [ADC.kicad_sch, RP2354B.kicad_sch, daughter.kicad_sch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]
2026-06-01 added back display brightness, removed adc allert on pcb
    [ADC.kicad_sch, RP2354B.kicad_sch, disp.kicad_sch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]
2026-06-01 switched the two i2c pins on the rpi for the adc
    [RP2354B.kicad_sch, hackxpansion.kicad_pcb]
2026-06-02 switcheed bank 0 pin 5 and 6 cuz i messed up
    [RP2354B.kicad_sch, hackxpansion.kicad_pcb]
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2026-06-07 added 3d model to rp inductor, moved silkscreen around
    [hackxpansion.kicad_pcb]
2026-06-07 updated footprint 3d model from wrl to step
    [hackxpansion.kicad_pcb]
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2026-06-09 added mounting holes to two button module
    [two_button.kicad_pcb, two_button.kicad_sch]
2026-06-09 moved display connector up 1.6mm
    [hackxpansion.kicad_pcb]
2026-06-10 fixed 3d model for pico blade connector
    [hackxpansion.kicad_pcb]
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2026-06-10 moved usb c 3d to project folder
    [hackxpansion.kicad_pcb]
2026-06-12 moved fpc connector inwords
    [hackxpansion.kicad_pcb]
2026-06-17 added four button module
    [four_button.kicad_pcb, four_button.kicad_sch]
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2026-06-21 added series resistor to module power rail, so it can now do hotswap
    [disp.kicad_sch, hackxpansion.kicad_pcb, module.kicad_sch]
2026-06-23 changed out fpc connector, fixed usb dp width
    [disp.kicad_sch, hackxpansion.kicad_pcb]
2026-06-23 fixed issues with new fpc
    [hackxpansion.kicad_pcb]
2026-06-24 fixed unconnected 3v3 via next to display
    [hackxpansion.kicad_pcb]
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2026-06-27 added a bunch of gnd return VIAs, removed via group
    [hackxpansion.kicad_pcb]
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2026-06-28 added resistor values to the four and two button modules
    [four_button.kicad_sch, two_button.kicad_pcb, two_button.kicad_sch]
2026-06-28 updated two and four button pcb with new lcsc part nums
    [four_button.kicad_pcb, two_button.kicad_pcb]
2026-06-28 updated lcsc part nums for modules with correct footprint
    [four_button.kicad_pcb, four_button.kicad_sch, two_button.kicad_pcb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]
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2026-07-19 let gpt 5.6 sol max loose on the firmware
    I want through all the changes it made, and will fix the issues I found
    in future commits
    [adc.rs, adc_mapping.rs, allocator.rs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]
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2026-07-24 fixed boot issues, switchted adc over to bitbang i2c
    [adc.rs, adc_mapping.rs, core_driver.rs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]
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2026-07-24 inverted display color, added button aliasing, added 4 button driver
    [buttons.rs, display.rs, lib.rs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]
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2026-07-26 finished schematic with some improvements and fixed library paths
    [audio_module.kicad_sch]
2026-07-26 started pcb layout and traces for tutorial module
    [audio_module.kicad_pcb, audio_module.kicad_sch]
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2026-07-28 Started on a sbc expansion board with F1C100s
    [CPU.kicad_sch, PMIC.kicad_sch, linux_soc.kicad_pcb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]
2026-07-29 fixed some bugs with nes
    [lib.rs]
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2026-07-30 Added Crystal and SD card to linux soc card
    [CPU.kicad_sch, SD_CARD.kicad_sch]
2026-08-01 first card small fix and first driver progress
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2026-08-02 Almost finished schematic and started on layout idea's of hdmi module
    [RGB-HDMI.kicad_sch, SPI-RGB.kicad_sch, hdmi.kicad_pcb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]
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
